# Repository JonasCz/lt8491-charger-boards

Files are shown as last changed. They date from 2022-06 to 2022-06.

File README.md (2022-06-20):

# LT8491 MPPT boosting solar charge controller mainboard

**PCB layout**:

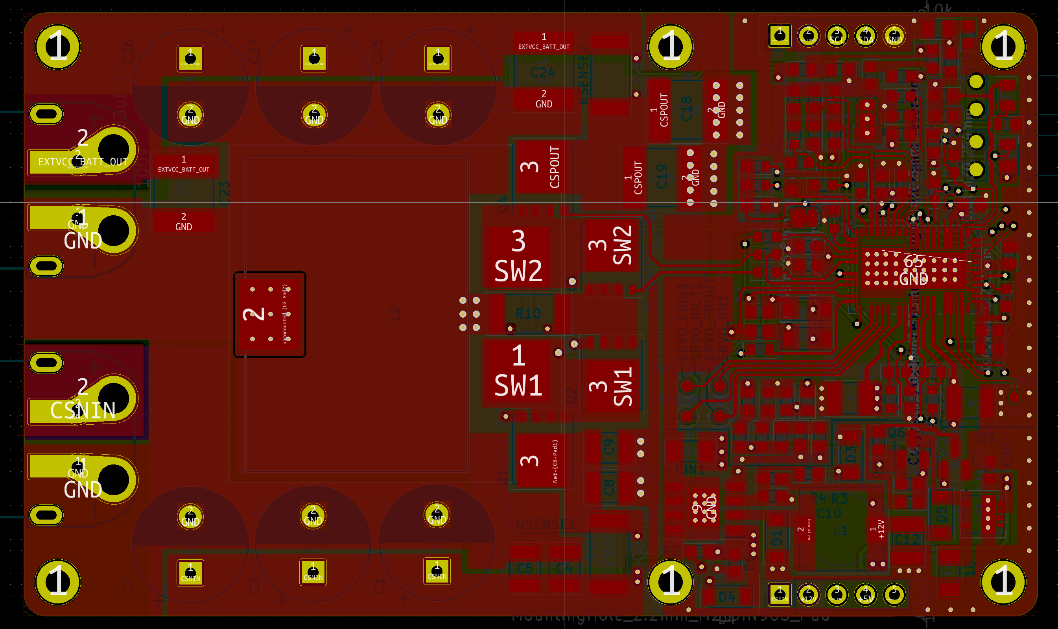
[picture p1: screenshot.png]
Screenshot of PCB layout


**Description**: This project started out with the goal of reimplementing [Craig Peacock's design](https://circuitmaker.com/Projects/Details/Craig-Peacock-4/LT8490-Buck-Boost-Multi-Chemistry-Battery-Charger-with-MPPT) in KiCad, while also making it more compact;

**Status**: Test PCB assembled: LT8491 starts and communicates over i2C, but performance is unusably poor. Unsure why.

**Features**:

* Auxilary switching power supply to power additional future display board, can be enabled/disabled at runtime for power saving
* As compact as possible while keeping the board single sided
* High performance and efficiency (hopefully)
* XT60 connectors
* 60v max in and out

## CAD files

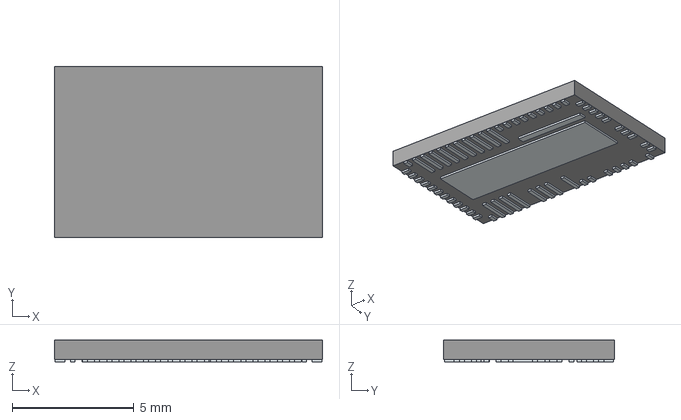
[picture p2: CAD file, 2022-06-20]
LT8491EUKJ#PBF/3D/LT8491EUKJ#PBF.stp
11.0 x 7.00 x 0.9 mm
Pins

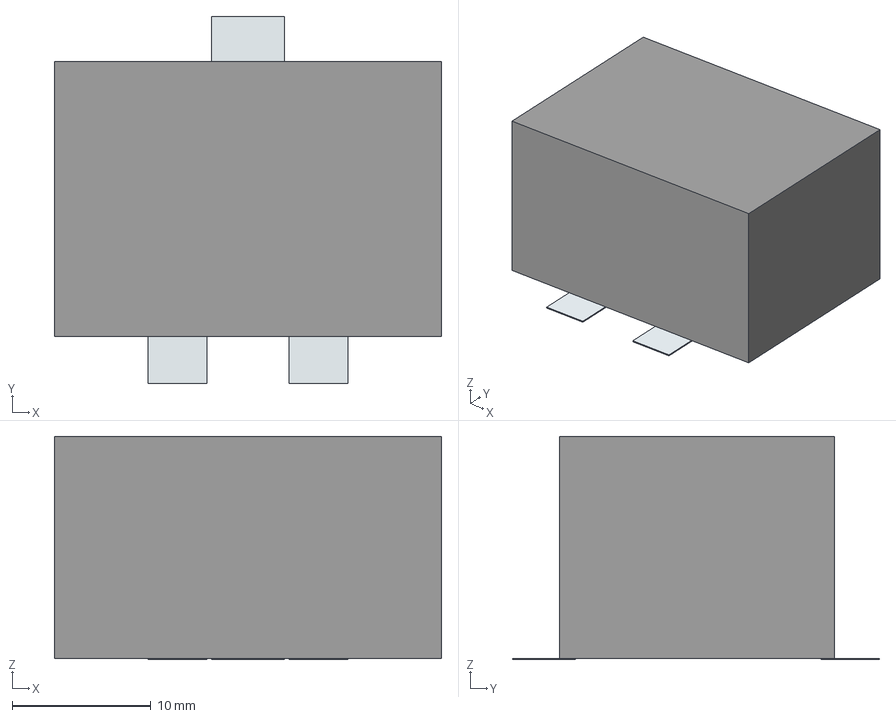
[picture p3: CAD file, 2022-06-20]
PQ2614BLA-150K/3D/PQ2614BLA-4R7K.stp
27.9 x 26.4 x 16.1 mm
Pins

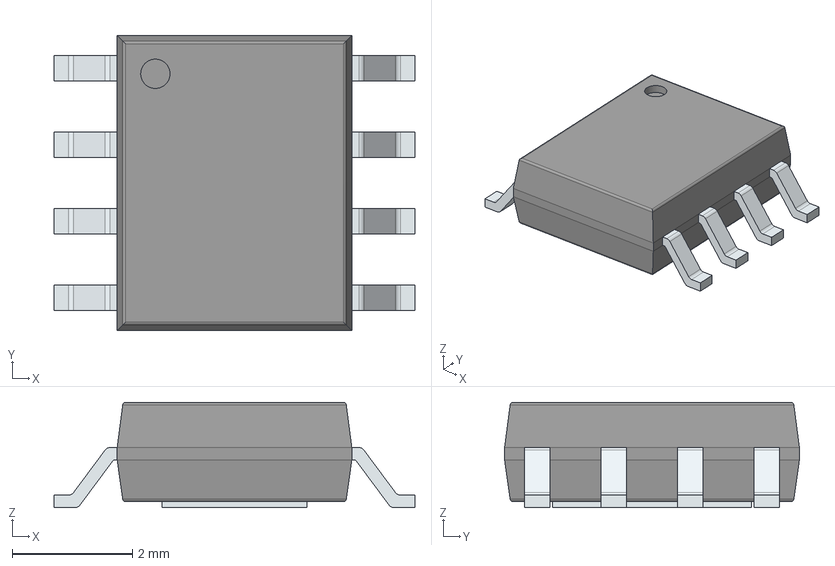
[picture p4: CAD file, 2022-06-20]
XL7005A/3D/XL7005A.stp
6.00 x 4.90 x 1.75 mm
PinsArrayLR
ThermalPad

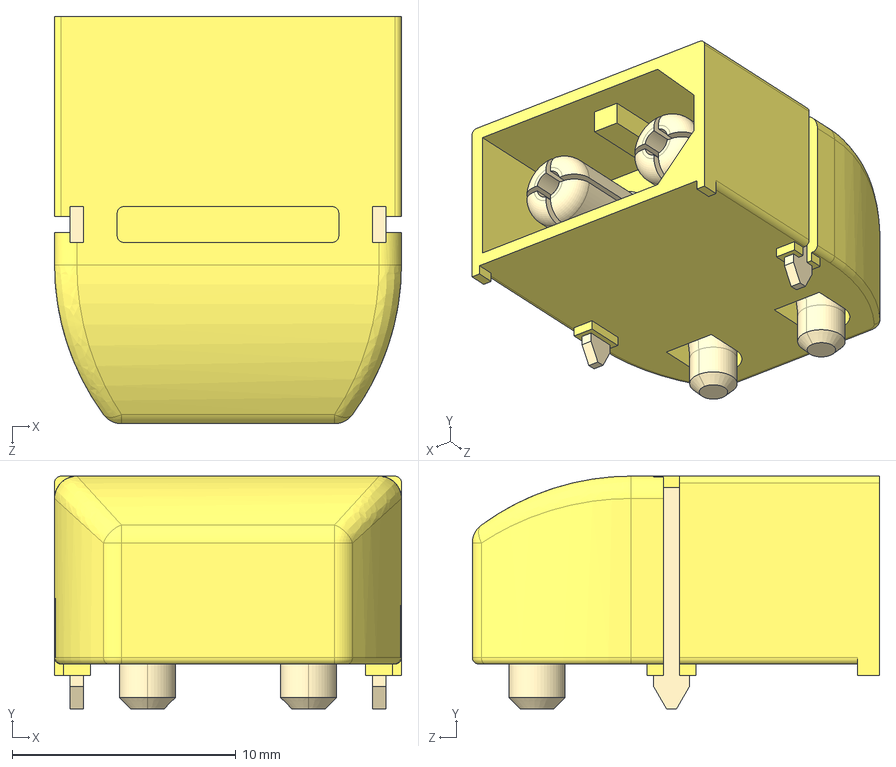
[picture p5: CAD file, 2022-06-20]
XT60-PW-M/XT60-PW-M.STEP
15.5 x 10.4 x 18.2 mm

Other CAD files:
LT8491EUKJ#PBF/3D/LT8491EUKJ#PBF.stl
NCP781BMN050TAG/3D/NCP781BMN050TAG.stl
PQ2614BLA-150K/3D/PQ2614BLA-4R7K.stl
XL7005A/3D/XL7005A.stl

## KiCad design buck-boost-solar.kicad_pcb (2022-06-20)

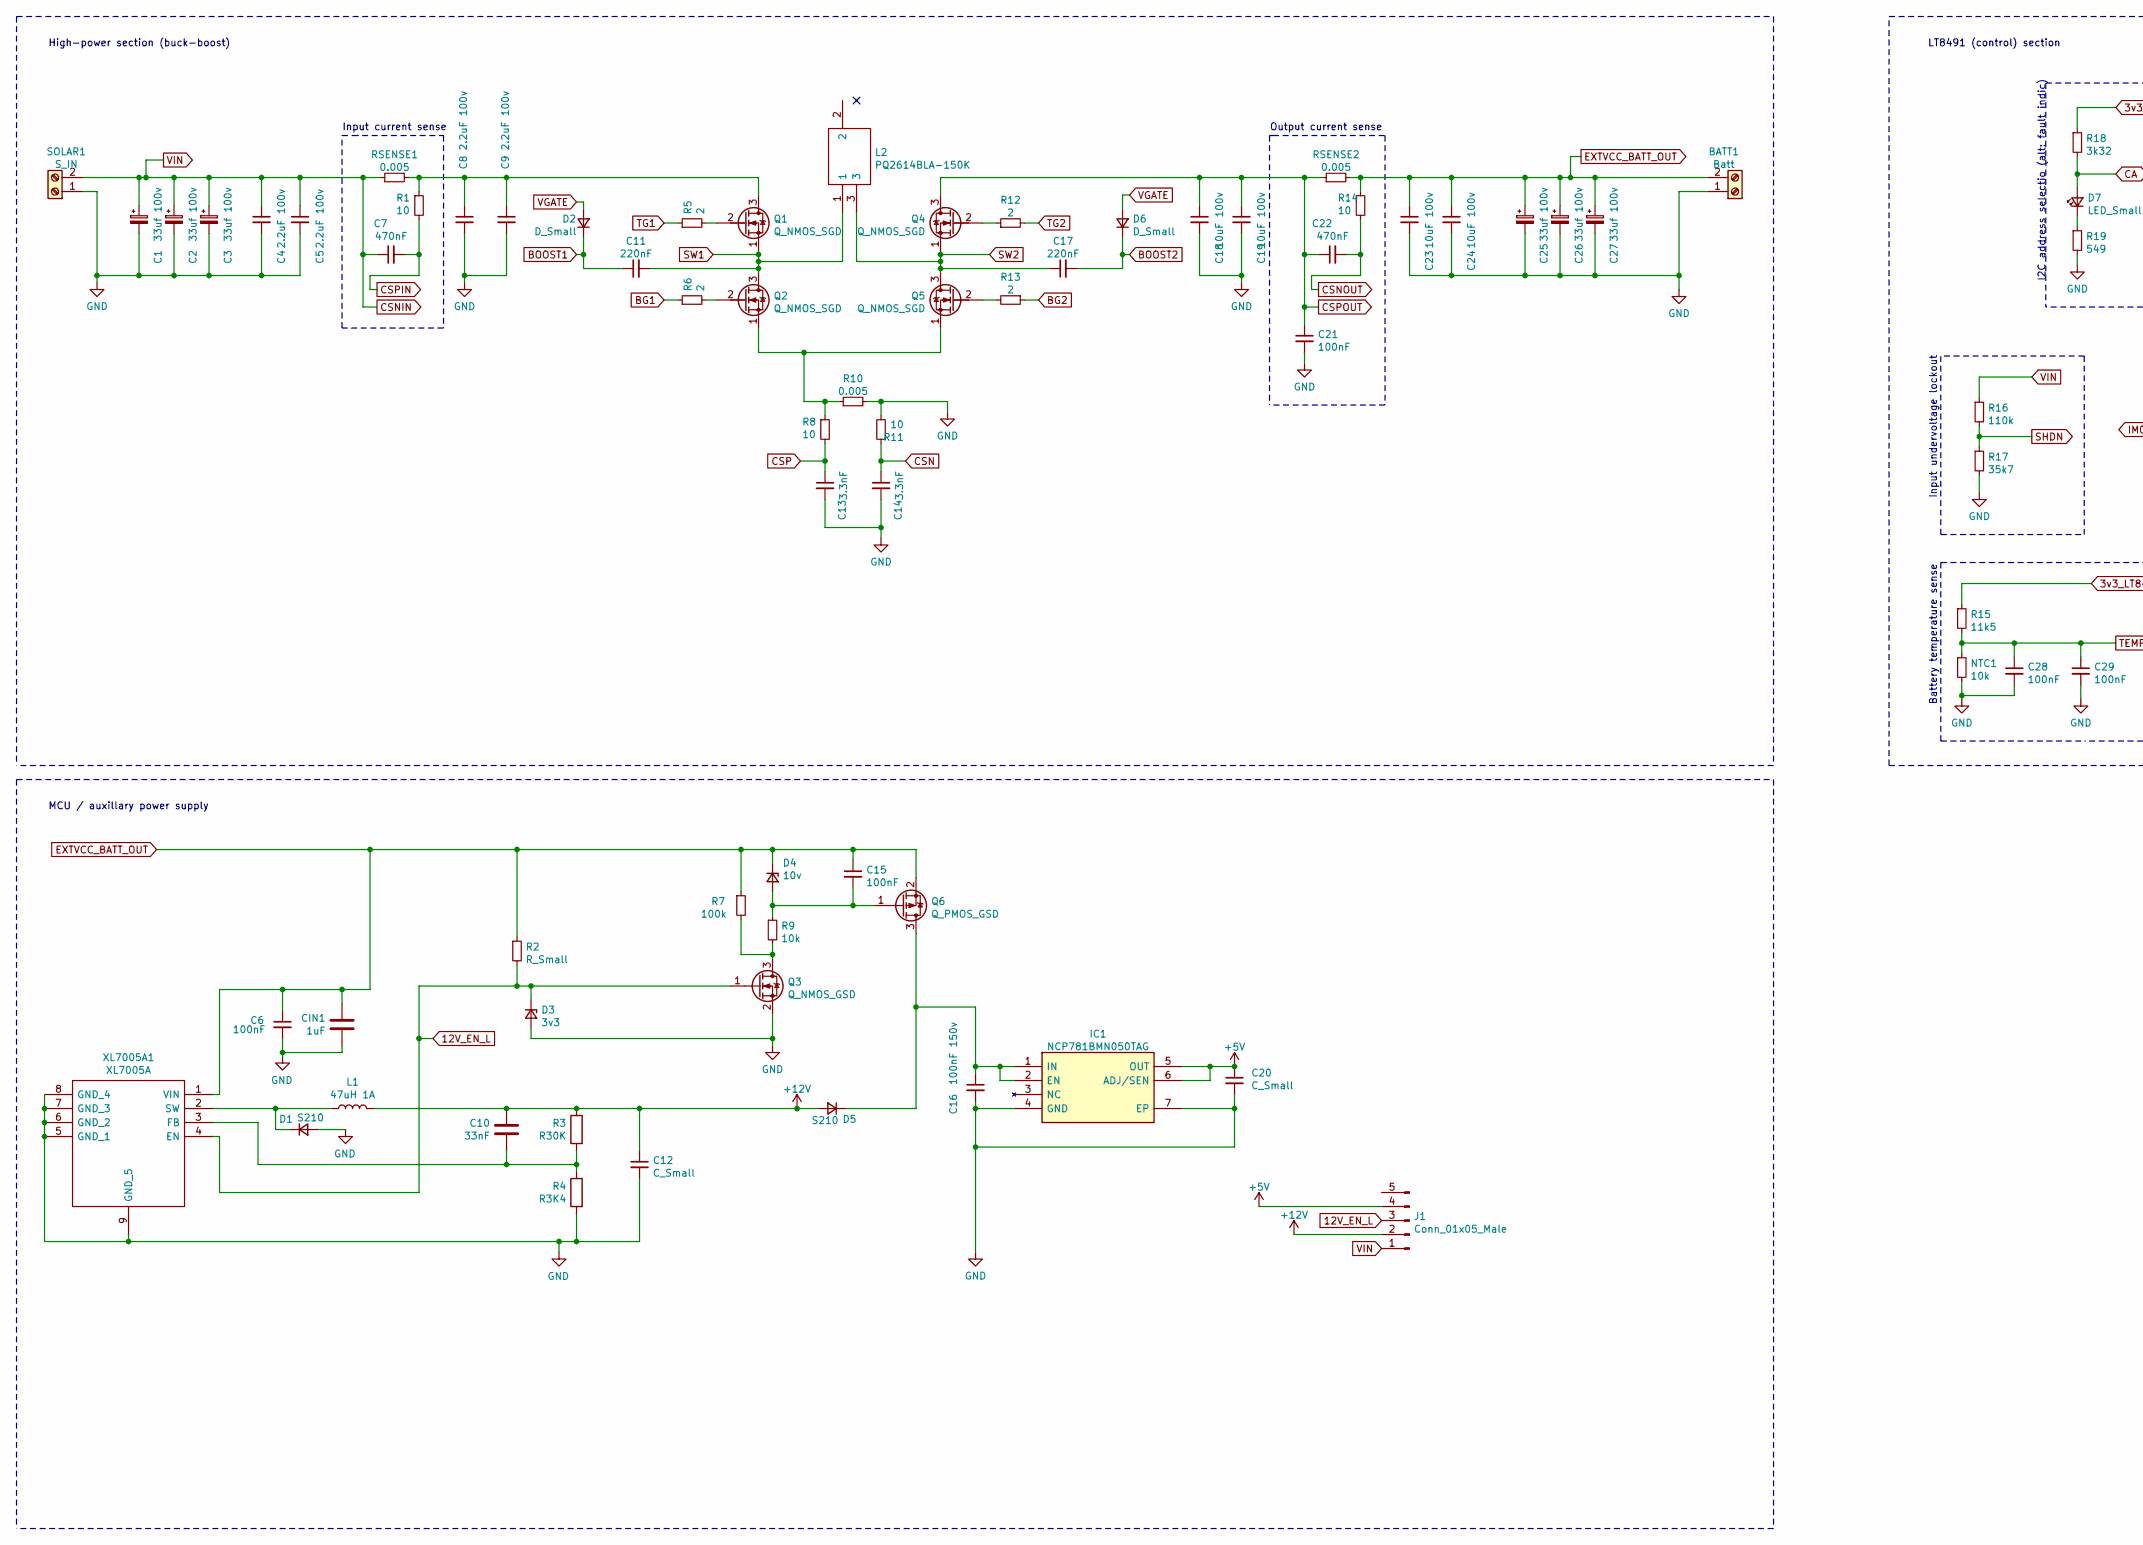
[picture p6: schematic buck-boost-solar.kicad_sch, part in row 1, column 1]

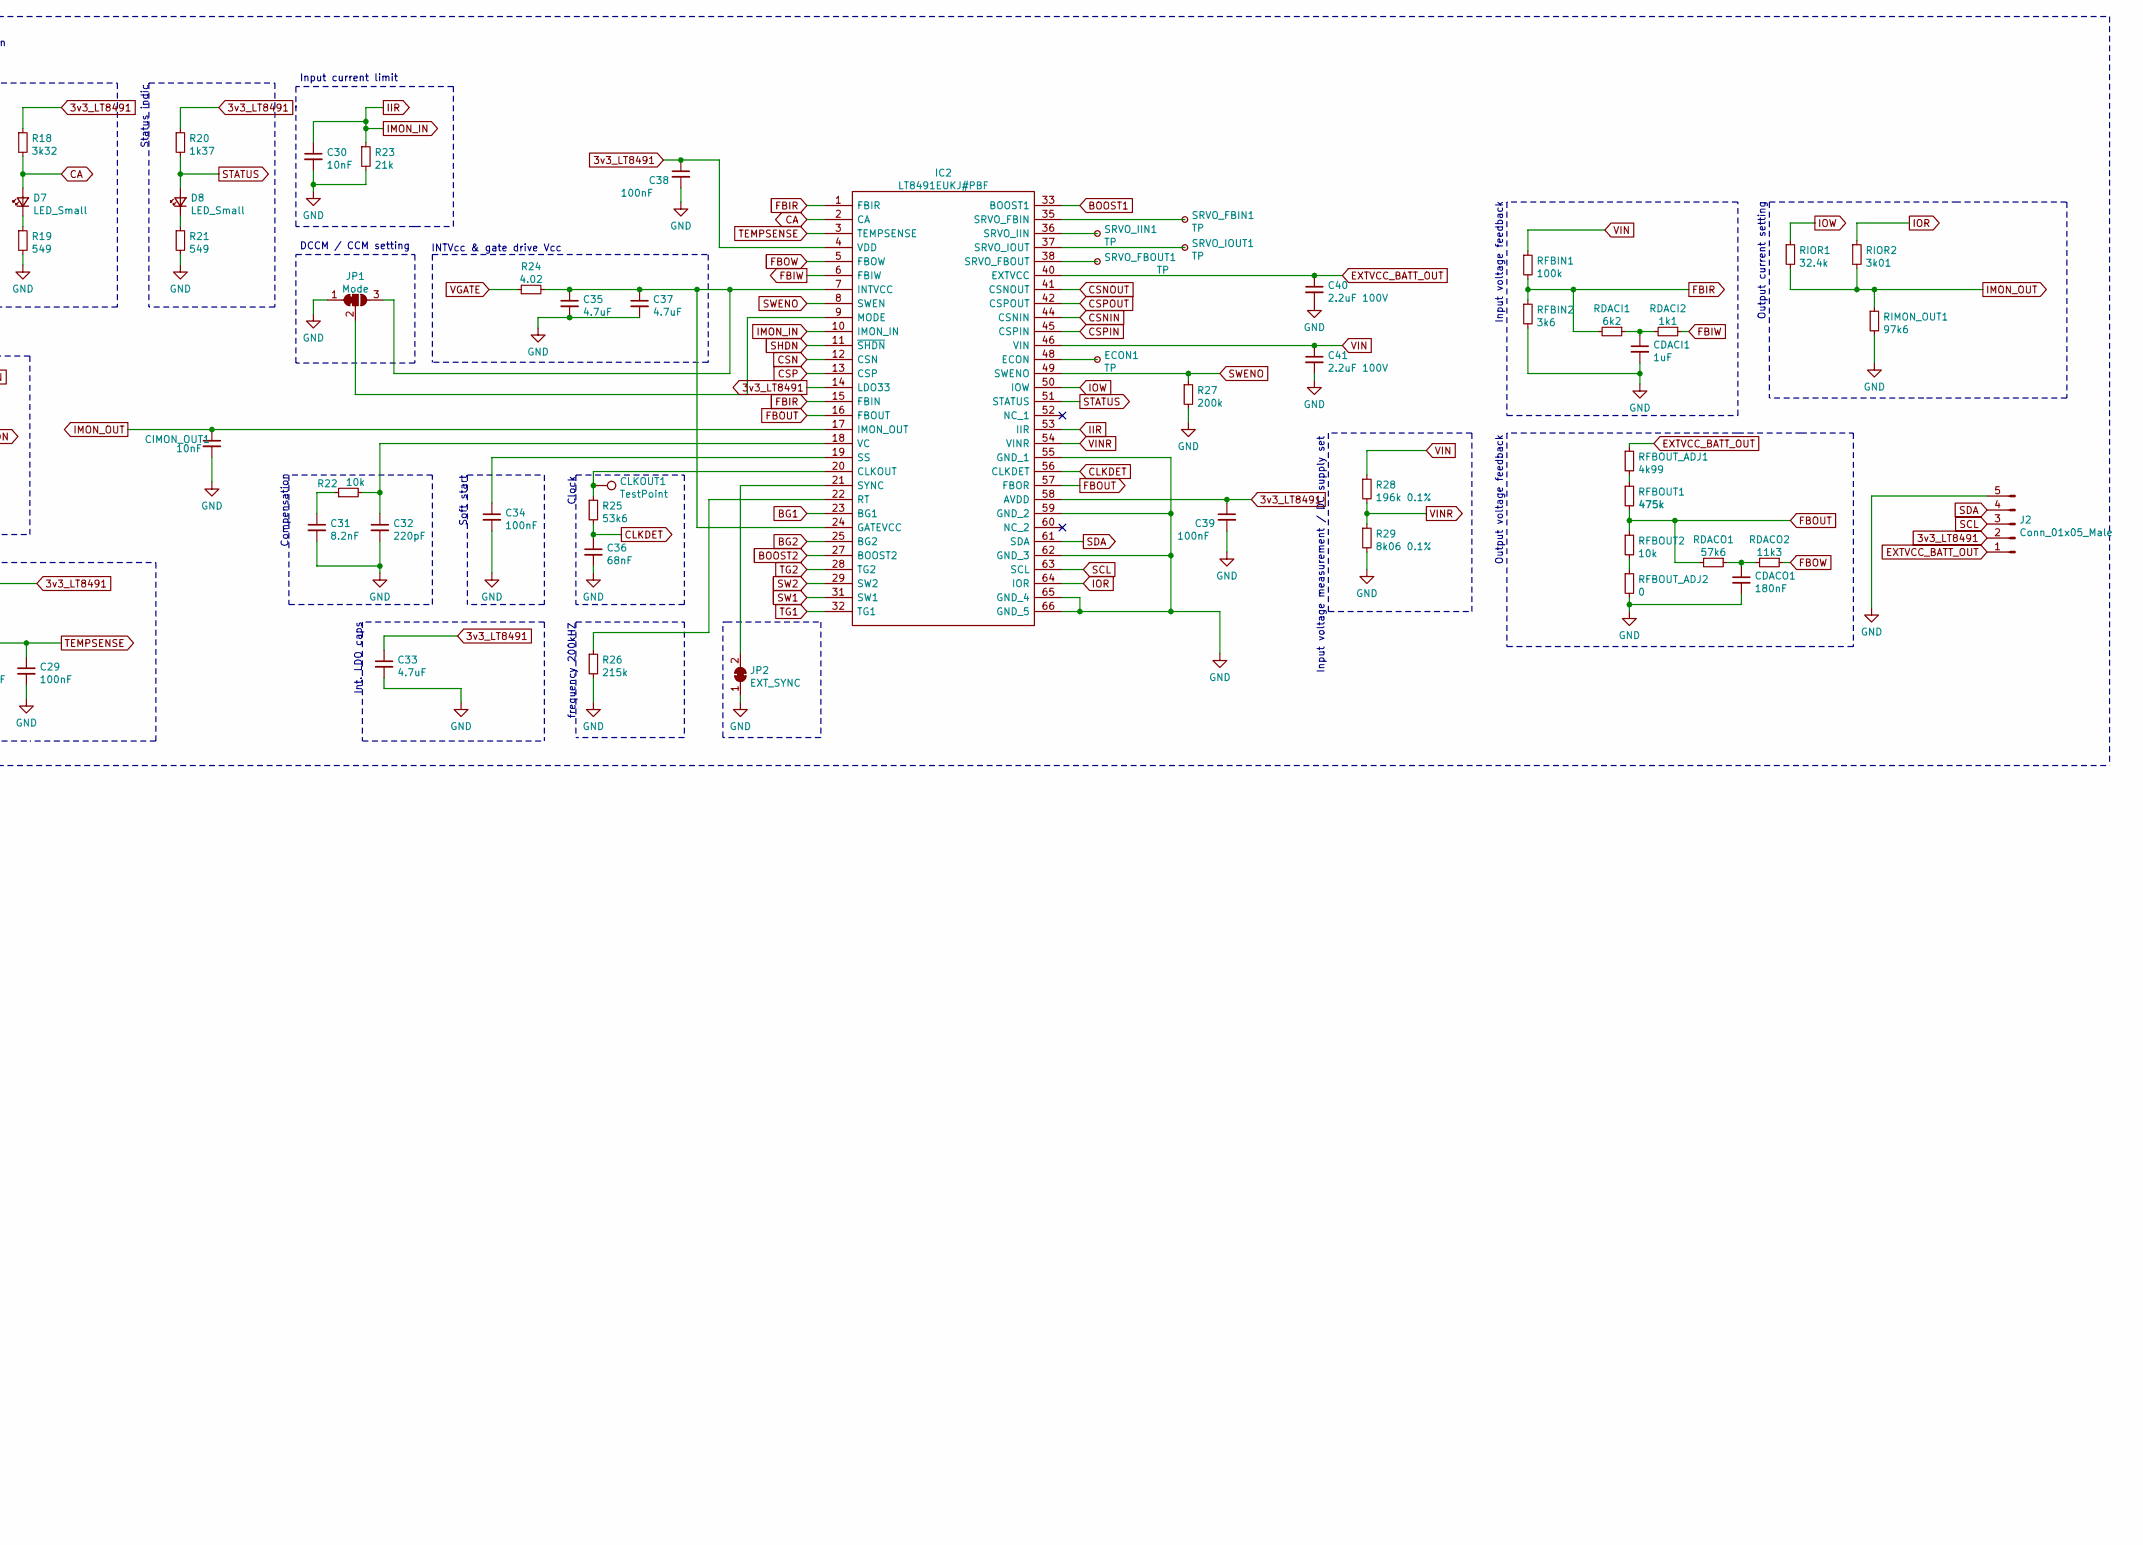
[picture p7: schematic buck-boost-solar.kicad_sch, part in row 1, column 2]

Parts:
BATT1: Batt; Amass_XT60PW-M_Kombifootprint; LCSC Part Number C98732
C1, C2, C3, C25, C26, C27: 33uf 100v; CP_Radial_D10.0mm_P5.00mm; LCSC Part Number C407997
C4, C5, C8, C9: 2.2uF 100v; C_1210_3225Metric; LCSC Part Number C338133
C6, C21, C28, C29, C34, C38, C39: 100nF; C_0603_1608Metric; LCSC Part Number C696916
C7, C22: 470nF; C_0603_1608Metric; LCSC Part Number C1623
C10: 33nF; C_0603_1608Metric
C11, C17: 220nF; C_0603_1608Metric; LCSC Part Number C335532
C12: C_Small; C_1210_3225Metric
C13, C14: 3.3nF; C_0603_1608Metric; LCSC Part Number C482476
C15: 100nF; C_0603_1608Metric
C16: 100nF 150v; C_1206_3216Metric
C18, C19, C23, C24: 10uF 100v; C_2220_5650Metric; LCSC Part Number C153035
C20: C_Small; C_0603_1608Metric
C30: 10nF; C_0603_1608Metric; LCSC Part Number C100042
C31: 8.2nF; C_0603_1608Metric; LCSC Part Number C376849
C32: 220pF; C_0603_1608Metric; LCSC Part Number C376820
C33, C35, C37: 4.7uF; C_0603_1608Metric; LCSC Part Number C69335
C36: 68nF; C_0603_1608Metric; LCSC Part Number C237232
C40, C41: 2.2uF 100V; C_1210_3225Metric; LCSC Part Number C338133
CDACI1: 1uF; C_0603_1608Metric; LCSC Part Number C5673
CDACO1: 180nF; C_0603_1608Metric; LCSC Part Number C519442
CIMON_OUT1: 10nF; C_0603_1608Metric; LCSC Part Number C100042
CIN1: 1uF; C_1206_3216Metric
CLKOUT1: TestPoint; TestPoint_Pad_D1.0mm
D1, D5: S210; D_SOD-123
D2, D6: D_Small; D_SOD-123; LCSC Part Number C258207
D3: 3v3; D_SOD-123
D4: 10v; D_SOD-123
D7, D8: LED_Small; D_0805_2012Metric; LCSC Part Number C72037
ECON1: TP; TestPoint_Pad_D1.0mm
IC1: NCP781BMN050TAG; Manufacturer_Part_Number NCP781BMN050TAG; Mouser Part Number 863-NCP781BMN050TAG
IC2: LT8491EUKJ#PBF; LT8491EUKJ; Manufacturer_Part_Number LT8491EUKJ#PBF; Mouser Part Number 584-LT8491EUKJ#PBF
J1, J2: Conn_01x05_Male; PinHeader_1x05_P2.54mm_Vertical
JP1: Mode; SolderJumper-3_P1.3mm_Bridged2Bar12_RoundedPad1.0x1.5mm
JP2: EXT_SYNC; SolderJumper-2_P1.3mm_Bridged_RoundedPad1.0x1.5mm
L1: 47uH 1A; L_7.3x7.3_H4.5
L2: PQ2614BLA-150K; PQ2614BLA100K; Manufacturer_Part_Number PQ2614BLA-150K; Mouser Part Number 652-PQ2614BLA-150K
NTC1: 10k; R_0805_2012Metric; LCSC Part Number C338623
Q1, Q2, Q4, Q5: Q_NMOS_SGD; TDSON-8-1-SGD; LCSC Part Number C148260
Q3: Q_NMOS_GSD; SOT-23; LCSC Part Number C397175
Q6: Q_PMOS_GSD; SOT-23; LCSC Part Number C700960
R1, R8, R11, R14: 10; R_0603_1608Metric; LCSC Part Number C384297
R2: R_Small; R_0603_1608Metric
R3: R30K; R_0603_1608Metric
R4: R3K4; R_0603_1608Metric
R5, R6, R12, R13: 2; R_0603_1608Metric; LCSC Part Number C286596
R7: 100k; R_0603_1608Metric
R9: 10k; R_0603_1608Metric
R10: 0.005; R_2512_6332Metric; LCSC Part Number C457120
R15: 11k5; R_0603_1608Metric; LCSC Part Number C25949
R16: 110k; R_0603_1608Metric; LCSC Part Number C25805
R17: 35k7; R_0603_1608Metric; LCSC Part Number C23027
R18: 3k32; R_0603_1608Metric; LCSC Part Number C321860
R19, R21: 549; R_0603_1608Metric; LCSC Part Number C23079
R20: 1k37; R_0603_1608Metric; LCSC Part Number C22839
R22: 10k; R_0603_1608Metric; LCSC Part Number C25804
R23: 21k; R_0603_1608Metric; LCSC Part Number C22956
R24: 4.02; R_0603_1608Metric; LCSC Part Number C322168
R25: 53k6; R_0603_1608Metric; LCSC Part Number C23074
R26: 215k; R_0603_1608Metric; LCSC Part Number C22954
R27: 200k; R_0603_1608Metric; LCSC Part Number C304068
R28: 196k 0.1%; R_0603_1608Metric; LCSC Part Number C705733
R29: 8k06 0.1%; R_0603_1608Metric; LCSC Part Number C304068
RDACI1: 6k2; R_0603_1608Metric; LCSC Part Number C319499
RDACI2: 1k1; R_0603_1608Metric; LCSC Part Number C351674
RDACO1: 57k6; R_0603_1608Metric; LCSC Part Number C243028
RDACO2: 11k3; R_0603_1608Metric; LCSC Part Number C491110
RFBIN1: 100k; R_0603_1608Metric; LCSC Part Number C335088
RFBIN2: 3k6; R_0603_1608Metric; LCSC Part Number C318132
RFBOUT1: 475k; R_0603_1608Metric; LCSC Part Number C503464
RFBOUT2: 10k; R_0603_1608Metric; LCSC Part Number C309083
RFBOUT_ADJ1: 4k99; R_0603_1608Metric; LCSC Part Number C335079
RFBOUT_ADJ2: 0; R_0603_1608Metric; LCSC Part Number C286596
RIMON_OUT1: 97k6; R_0603_1608Metric; LCSC Part Number C23269
RIOR1: 32.4k; R_0603_1608Metric; LCSC Part Number C170561
RIOR2: 3k01; R_0603_1608Metric; LCSC Part Number C168308
RSENSE1, RSENSE2: 0.005; R_2512_6332Metric; LCSC Part Number C457120
SOLAR1: S_IN; Amass_XT60PW-M_Kombifootprint; LCSC Part Number C428722
SRVO_FBIN1: TP; TestPoint_Pad_D1.0mm
SRVO_FBOUT1: TP; TestPoint_Pad_D1.0mm
SRVO_IIN1: TP; TestPoint_Pad_D1.0mm
SRVO_IOUT1: TP; TestPoint_Pad_D1.0mm
XL7005A1: XL7005A; SOIC127P600X175-9N; Manufacturer_Part_Number XL7005A; LCSC Part Number C50848

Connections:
3v3_LT8491: C33.1, C38.1, C39.1, IC2.4 (VDD), IC2.14 (LDO33), IC2.58 (AVDD), J2.2, R15.1, R18.1, R20.1
12V_EN_L: D3.1 (K), J1.3, Q3.1 (G), R2.2, XL7005A1.4 (EN)
+5V: C20.1, IC1.5 (OUT), IC1.6 (ADJ/SEN), J1.4
+12V: C10.1, C12.1, D5.2 (A), J1.2, L1.1, R3.1
BG1: IC2.23 (BG1), R6.1
BG2: IC2.25 (BG2), R13.1
BOOST1: C11.1, D2.1 (K), IC2.33 (BOOST1)
BOOST2: C17.2, D6.1 (K), IC2.27 (BOOST2)
CA: D7.2 (A), IC2.2 (CA), R18.2
CLKDET: C36.1, IC2.56 (CLKDET), R25.2
CSN: C14.1, IC2.12 (CSN), R11.1
CSNIN: C1.1, C2.1, C3.1, C4.1, C5.1, C7.1, C41.1, IC2.44 (CSNIN), IC2.46 (VIN), J1.1, R16.1, R28.1, RFBIN1.1, RSENSE1.1, SOLAR1.2
CSNOUT: C22.2, IC2.41 (CSNOUT), R14.2
CSP: C13.1, IC2.13 (CSP), R8.2
CSPIN: C7.2, IC2.45 (CSPIN), R1.2
CSPOUT: C18.1, C19.1, C21.1, C22.1, IC2.42 (CSPOUT), Q4.3 (D), RSENSE2.1
EXTVCC_BATT_OUT: BATT1.2, C6.1, C15.1, C23.1, C24.1, C25.1, C26.1, C27.1, C40.1, CIN1.1, D4.1 (K), IC2.40 (EXTVCC), J2.1, Q6.2 (S), R2.1, R7.1, R14.1, RFBOUT_ADJ1.1, RSENSE2.2, XL7005A1.1 (VIN)
FBIR: IC2.1 (FBIR), IC2.15 (FBIN), RDACI1.2, RFBIN1.2, RFBIN2.1
FBIW: IC2.6 (FBIW), RDACI2.1
FBOUT: IC2.16 (FBOUT), IC2.57 (FBOR), RDACO1.2, RFBOUT1.2, RFBOUT2.1
FBOW: IC2.5 (FBOW), RDACO2.1
GND: BATT1.1, C1.2, C2.2, C3.2, C4.2, C5.2, C6.2, C8.2, C9.2, C12.2, C13.2, C14.2, C16.2, C18.2, C19.2, C20.2, C21.2, C23.2, C24.2, C25.2, C26.2, C27.2, C28.2, C29.2, C30.2, C31.2, C32.2, C33.2, C34.2, C35.2, C36.2, C37.2, C38.2, C39.2, C40.2, C41.2, CDACI1.2, CDACO1.2, CIMON_OUT1.2, CIN1.2, D1.2 (A), D3.2 (A), IC1.4 (GND), IC1.7 (EP), IC2.55 (GND_1), IC2.59 (GND_2), IC2.62 (GND_3), IC2.65 (GND_4), IC2.66 (GND_5), J2.5, JP1.1 (A), JP2.1 (A), NTC1.2, Q3.2 (S), R4.2, R10.2, R11.2, R17.2, R19.2, R21.2, R23.2, R26.2, R27.2, R29.2, RFBIN2.2, RFBOUT_ADJ2.2, RIMON_OUT1.2, SOLAR1.1, XL7005A1.5 (GND_1), XL7005A1.6 (GND_2), XL7005A1.7 (GND_3), XL7005A1.8 (GND_4), XL7005A1.9 (GND_5)
IIR: C30.1, IC2.10 (IMON_IN), IC2.53 (IIR), R23.1
IMON_OUT: CIMON_OUT1.1, IC2.17 (IMON_OUT), RIMON_OUT1.1, RIOR1.2, RIOR2.2
IOR: IC2.64 (IOR), RIOR2.1
IOW: IC2.50 (IOW), RIOR1.1
unnamed: C8.1, C9.1, Q1.3 (D), R1.1, RSENSE1.2
unnamed: C10.2, R3.2, R4.1, XL7005A1.3 (FB)
unnamed: C15.2, D4.2 (A), Q6.1 (G), R9.1
unnamed: C31.1, R22.1
unnamed: C32.1, IC2.18 (VC), R22.2
unnamed: C34.1, IC2.19 (SS)
unnamed: C35.1, C37.1, IC2.7 (INTVCC), IC2.24 (GATEVCC), JP1.3 (B), R24.2
unnamed: CDACI1.1, RDACI1.1, RDACI2.2
unnamed: CDACO1.1, RDACO1.1, RDACO2.2
unnamed: CLKOUT1.1, IC2.20 (CLKOUT), R25.1
unnamed: D1.1 (K), L1.2, XL7005A1.2 (SW)
unnamed: C16.1, D5.1 (K), IC1.1 (IN), IC1.2 (EN), Q6.3 (D)
unnamed: D7.1 (K), R19.1
unnamed: D8.1 (K), R21.1
unnamed: ECON1.1, IC2.48 (ECON)
unnamed: IC2.9 (MODE), JP1.2 (C)
unnamed: IC2.21 (SYNC), JP2.2 (B)
unnamed: IC2.22 (RT), R26.1
unnamed: IC2.35 (SRVO_FBIN), SRVO_FBIN1.1
unnamed: IC2.36 (SRVO_IIN), SRVO_IIN1.1
unnamed: IC2.37 (SRVO_IOUT), SRVO_IOUT1.1
unnamed: IC2.38 (SRVO_FBOUT), SRVO_FBOUT1.1
unnamed: Q1.2 (G), R5.2
unnamed: Q2.1 (S), Q5.1 (S), R8.1, R10.1
unnamed: Q2.2 (G), R6.2
unnamed: Q3.3 (D), R7.2, R9.2
unnamed: Q4.2 (G), R12.1
unnamed: Q5.2 (G), R13.2
unnamed: RFBOUT1.1, RFBOUT_ADJ1.2
unnamed: RFBOUT2.2, RFBOUT_ADJ2.1
SCL: IC2.63 (SCL), J2.3
SDA: IC2.61 (SDA), J2.4
SHDN: IC2.11 (~SHDN), R16.2, R17.1
STATUS: D8.2 (A), IC2.51 (STATUS), R20.2
SW1: C11.2, IC2.31 (SW1), L2.1, Q1.1 (S), Q2.3 (D)
SW2: C17.1, IC2.29 (SW2), L2.3, Q4.1 (S), Q5.3 (D)
SWENO: IC2.8 (SWEN), IC2.49 (SWENO), R27.1
TEMPSENSE: C28.1, C29.1, IC2.3 (TEMPSENSE), NTC1.1, R15.2
TG1: IC2.32 (TG1), R5.1
TG2: IC2.28 (TG2), R12.2
VGATE: D2.2 (A), D6.2 (A), R24.1
VINR: IC2.54 (VINR), R28.2, R29.1

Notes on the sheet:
High-power section (buck-boost)
MCU / auxillary power supply
Input current sense
Output current sense
LT8491 (control) section
Input undervoltage lockout
Battery temperature sense
I2C address selectio (alt: fault indic)
Status indic
Compensation
Input current limit
DCCM / CCM setting
Int. LDO caps
INTVcc & gate drive Vcc
Soft start
Clock
frequency 200kHZ
Input voltage measurement / DC supply set
Input voltage feedback
Output voltage feedback
Output current setting

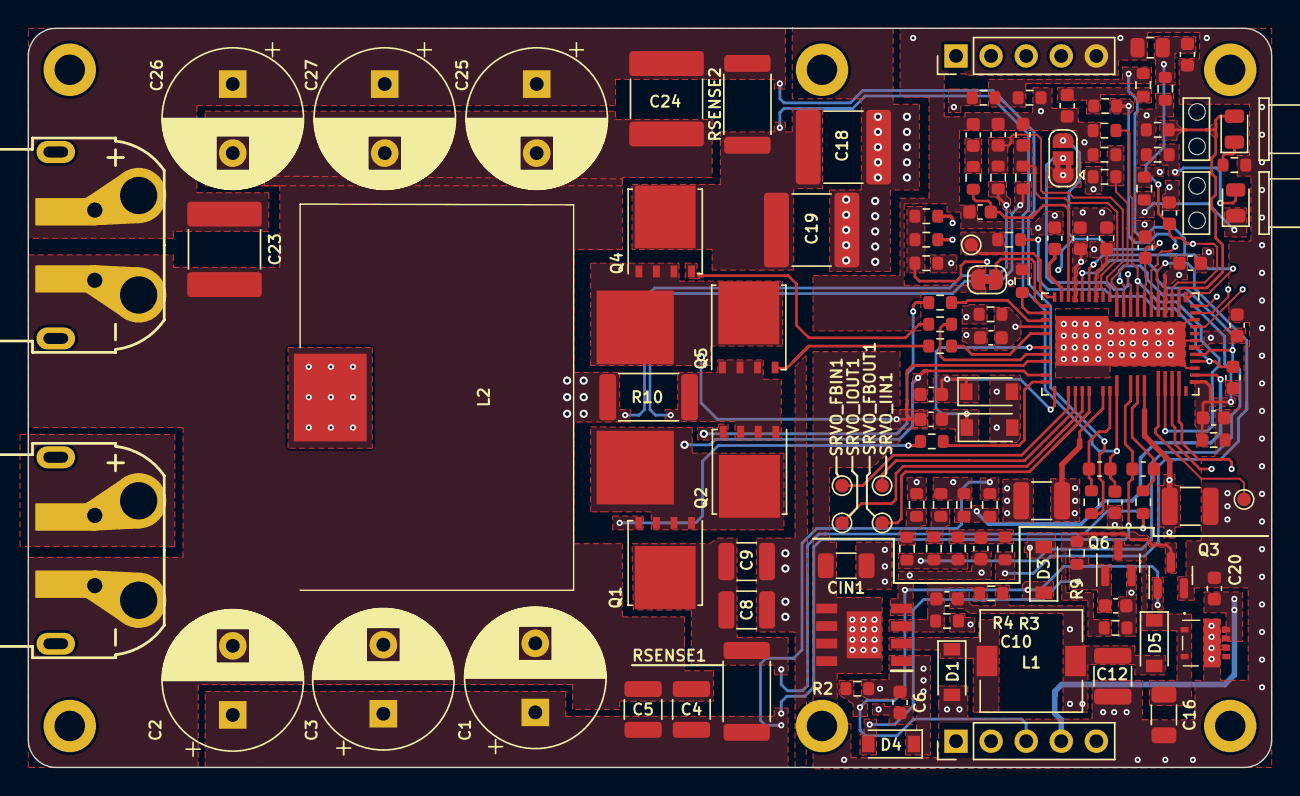
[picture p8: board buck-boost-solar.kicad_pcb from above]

Board: 4 copper layers, 90.0 x 53.5 mm, 121 parts (0 on the bottom side), 68 nets.

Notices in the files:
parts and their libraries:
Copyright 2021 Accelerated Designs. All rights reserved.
